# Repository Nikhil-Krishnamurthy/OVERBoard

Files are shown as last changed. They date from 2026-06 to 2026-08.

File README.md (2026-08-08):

# OVERBoard
This is my attempt at creating a custom keyboard with several unique features, this has a layer system that I have modified to work with specific tasks on my pc, I also have a 2.8 in screen to display custom text, ui, and macros. There is a full 78 led matrix, dual pi pico system, and 3 rotary encoders that interface in this system.   
# Key Features   
Full TKL Keyboard Matrix   
4 Layer Keyboard System   
3 Encoders Interfacing with the Layer System   
78 Led Matrix system   
320 x 240 2.8 inch display   
Custom UI and layer switching menus   
Computer interface and data transmission   
Custom 5A power system   

## Onshape-link:
https://cad.onshape.com/documents/a6bd6c4e9013194f1dc31777/w/de360b55982ee6c60ca7c4d4/e/a374dba059f4ceb7d8e6600d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 

# Flashing      
Flashing is done through two steps, compiling the C qmk file through QMK MSYS to compile to a uf2 file, which then can be flashed to the pi pico through holding the bootsel button and plugging it in to the usb power. Then just upload the new uf2 file to the pi pico. To flash the pi pico 2 for the display, you have to download the entire folder of the custom c++, and then through a terminal of your choice compile it. (I use vs code and i got it to work through there, idk about others). Then upload the second uf2 file to the pi pico 2 by holding the bootsel button and uploading it there.

# BOM   
78 [3 Pin Mechanical Keyboard Switches   ](https://www.amazon.com/Leezmark-Mechanical-Dustproof-Replacement-Keyboards/dp/B0GV78B48N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)   
78 [SK6812 Mini-E LEDs](https://www.amazon.com/Lizusidtsy-Similar-Individually-Addressable-500076361/dp/B0D62PYX62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)   
3 [EC11 Rotary encoders](https://www.amazon.com/CGNRONEAU-Potentiometer-Raspberry-Electronics-Projects/dp/B0G48Z8B9Q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)    
1 [Keycap Set](https://www.amazon.com/Womier-Doubleshot-Universal-Compatiability-Switches/dp/B0DD3MFZJH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)   
1 [Stabilizer Set](https://www.amazon.com/DUROCK-Stabilizers-Translucent-Keyboard-Mechanical/dp/B0B2RVN19F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)   
10 [0.1uF SMD 0805 Capacitors](https://www.digikey.com/en/products/detail/samsung-electro-mechanics/CL21B104KBCNNNC/3886661)   
2 [10uF SMD 1206 Capacitors](https://www.digikey.com/en/products/detail/taiyo-yuden/TMK316BJ106ML-T/1172143)   
83 [Through Hole Diodes](https://www.digikey.com/en/products/detail/onsemi/1N4148TR/458811)   
1 [Raspberry Pi Pico](https://www.digikey.com/en/products/detail/raspberry-pi/SC0915/13624793)   
1 [Raspberry Pi Pico 2](https://www.digikey.com/en/products/detail/raspberry-pi/SC1631/24627136)   
1 [SN74HCT245PWR](https://www.digikey.com/en/products/detail/texas-instruments/SN74HCT245PWR/376998)   
1 [Mini 560 5A 5V](https://www.amazon.com/ACEIRMC-Efficiency-Converter-Regulator-Stabilized/dp/B0C98GN9R5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)   
1 [Adafruit 5807 Power Evaluation Board](https://www.digikey.com/en/products/detail/adafruit-industries-llc/5807/21839778)   
1 [2.8 in 320 x 240 SPI Serial TFT display](https://www.amazon.com/DIANN-ILI9341-Display-320x240-Screen/dp/B0BNQBKFCT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)   
2 [PTS810_SJM_250](https://www.digikey.com/en/products/detail/c-k/PTS810SJK250SMTR-LFS/4176611)   
2 [4.7k SMD 0805 resistors](https://www.digikey.com/en/products/detail/panasonic-industry/ERA-6AEB472V/1465765)    
10 [10k SMD 0805 resistors](https://www.digikey.com/en/products/detail/stackpole-electronics-inc/RMCF0805FT10K0/1760676)   
## Extra Parts not part of BOM
9 [M3 Heat set inserts](https://www.amazon.com/HANGLIFE-Heat-Set-Threaded-Printing-Components/dp/B0CS6VZYL8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)   
9 [M3 Screws](https://www.amazon.com/Fgruh-750PCS-Assortment-Washers-Assorted/dp/B0FGV5FCBN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)   
2 [M2.5 Heat Set Inserts](https://www.amazon.com/HANGLIFE-Heat-Set-Threaded-Printing-Components/dp/B0CS6YVJYD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)   
2 [M2.5 Screws](https://www.amazon.com/Fgruh-750PCS-Assortment-Washers-Assorted/dp/B0FG2BYJSR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)   
1 [1Kg Matte Black Filament](https://www.amazon.com/ELEGOO-Filament-Dimensional-Accuracy-Carboard/dp/B0CFV3WF7P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)   
## PCB    
1 Custom Pcb    
## BOM as CSV Format    
[BOM.csv](https://github.com/Nikhil-Krishnamurthy/OVERBoard/blob/main/BOM.csv)     

# Full Render:    


# Schematic:   






# PCB:



# CAD:


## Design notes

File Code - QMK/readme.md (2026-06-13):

# overboard

overboard

*A short description of the keyboard/project*

* Keyboard Maintainer: [Nikhil-Krishnamurthy](https://github.com/Nikhil-Krishnamurthy)
* Hardware Supported: *The PCBs, controllers supported*
* Hardware Availability: *Links to where you can find this hardware*

Make example for this keyboard (after setting up your build environment):

    make overboard:default

Flashing example for this keyboard:

    make overboard:default:flash

See the [build environment setup](https://docs.qmk.fm/#/getting_started_build_tools) and the [make instructions](https://docs.qmk.fm/#/getting_started_make_guide) for more information. Brand new to QMK? Start with our [Complete Newbs Guide](https://docs.qmk.fm/#/newbs).

## Bootloader

Enter the bootloader in 3 ways:

* **Bootmagic reset**: Hold down the key at (0,0) in the matrix (usually the top left key or Escape) and plug in the keyboard
* **Physical reset button**: Briefly press the button on the back of the PCB - some may have pads you must short instead
* **Keycode in layout**: Press the key mapped to `QK_BOOT` if it is available

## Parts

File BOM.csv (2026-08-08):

Item | Quantity | Value | Link
Keyswitches | 1 | $14.99 | amazon.com/Leezmark-Mechanical-Dustproof-Replacement-Keyboards/dp/B0GV78B48N/ref=mp_s_a_1_20_sspa?crid=2GGAVKPX5GKH&dib=eyJ2IjoiMSJ9.BS9ZW8A40QZK6iI4UmdZkYcVp812RDtM8dzqQtxJq5kz5jddC0aGCLYpUDj6oWZM4geYAz7LL5dJKQJ_sMRCqYbuT9Zwzy20VnrTvVNVI-2PMGM8y_OT_gXPSKltVj0ZCmtBrzLAvtF8hVyPpS-bcG8HSGX4meJ7BWVw4GwyFBtzq-VV4k_-OB3_U29mYmabBNX5P_2u1xLUz0WsYM_SZg.sOaHXiIPD6Bd4c6RHFdcsiI9AAYZXd1oFGZit3XfvzE&dib_tag=se&keywords=mechanical+keyboard+switches&qid=1786102391&sprefix=mecha%2Caps%2C1667&sr=8-20-spons&xpid=P4xuzyhmO1Kis&sp_csd=d2lkZ2V0TmFtZT1zcF9waG9uZV9zZWFyY2hfbXRm&psc=1
SK6812 Mini-E | 1 | $10.95 | https://www.amazon.com/Lizusidtsy-Similar-Individually-Addressable-500076361/dp/B0D62PYX62?s=industrial
EC11 Rotary Encoder | 1 | $6.99 | https://www.amazon.com/CGNRONEAU-Potentiometer-Raspberry-Electronics-Projects/dp/B0G48Z8B9Q?s=industrial
Keycap Set | 1 | $13.99 | https://www.amazon.com/Womier-Doubleshot-Universal-Compatiability-Switches/dp/B0DD3MFZJH
Stabilizer Set (PCB Mount) | 1 | $18.99 | https://www.amazon.com/DUROCK-Stabilizers-Translucent-Keyboard-Mechanical/dp/B0B2RVN19F
0.1 uF 0805 Capacitor | 10 | $0.45 | https://www.digikey.com/en/products/detail/samsung-electro-mechanics/CL21B104KBCNNNC/3886661
10uF 1206 Capacitor | 2 | $0.52 | https://www.digikey.com/en/products/detail/taiyo-yuden/TMK316BJ106ML-T/1172143
1N4148TR Diode | 83 | $3.36 | https://www.digikey.com/en/products/detail/onsemi/1N4148TR/458811
Rasberry Pi Pico | 1 | $4.59 | https://www.digikey.com/en/products/detail/raspberry-pi/SC0915/13624793
Rasberry Pi Pico 2 | 1 | $6.12 | https://www.digikey.com/en/products/detail/raspberry-pi/SC1631/24627136
SN74HCT245PWR | 1 | $0.88 | https://www.digikey.com/en/products/detail/texas-instruments/SN74HCT245PWR/376998
Mini 560 5V 5A | 1 | $9.99 | https://www.amazon.com/ACEIRMC-Efficiency-Converter-Regulator-Stabilized/dp/B0C98GN9R5
Adafruit 5807 Power Delivery Board | 1 | $5.95 | https://www.digikey.com/en/products/detail/adafruit-industries-llc/5807/21839778
2.8 In SPI Display with Capacitive Touch | 1 | $11.99 | https://www.amazon.com/DIANN-ILI9341-Display-320x240-Screen/dp/B0BNQBKFCT?s=industrial
PTS810_SJM_250 | 2 | $1.16 | https://www.digikey.com/en/products/detail/c-k/PTS810SJK250SMTR-LFS/4176611
4.7k 0805 Resistor | 2 | $0.22 | https://www.digikey.com/en/products/detail/panasonic-industry/ERA-6AEB472V/1465765
10k 0805 Resistor | 10 | $0.27 | https://www.digikey.com/en/products/detail/stackpole-electronics-inc/RMCF0805FT10K0/1760676
Custom PCB | 1 | $55.60
Total |  | $167.01

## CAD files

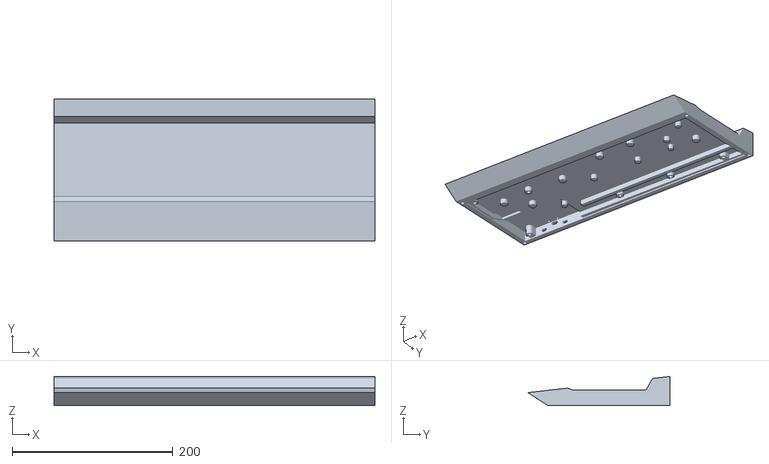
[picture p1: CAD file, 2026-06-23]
Cad-3D_Files/Keyboard_bottom.stl
398.9 x 176.7 x 36.2

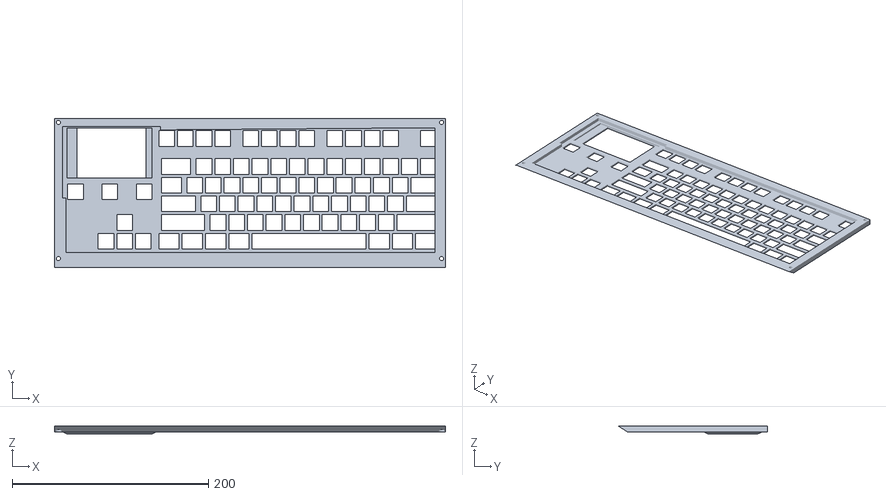
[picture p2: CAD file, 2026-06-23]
Cad-3D_Files/Keyboard_top.stl
398.9 x 151.9 x 7.80

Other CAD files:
Cad-3D_Files/Bottom_Case.step
Cad-3D_Files/Top_Case.step

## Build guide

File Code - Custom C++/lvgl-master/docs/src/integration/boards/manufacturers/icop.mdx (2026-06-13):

---
title: ICOP
description: ICOP makes industrial computer hardware and the development tools for them. ICOP offers an uncommon combination of hardware and software which distinguishes them from other board vendors.
---

ICOP makes industrial computer hardware and the development tools for them.
ICOP offers an uncommon combination of hardware and software which distinguishes
them from other board vendors.

For a start, their products are not evaluation boards. They are ready-to-use
industrial PCs. They are a complete solution electrically and mechanically.

They are programmed with the Arduino IDE. You write your embedded application
logic and UI using the Arduino framework and its library ecosystem. Arduino is a
great abstraction to solve real problems when it's available for a platform.
ICOP is one such platform. You have access to all the popular open source
Arduino libraries. There is also support for installing Windows 11 on it.

Inside most of ICOP's panel PCs is an x86 processor. They are DM&P Vortex86
series chips. They execute 32-bit i586 machine code. This has interesting
implications, especially since the programming environment is as low-level as Arduino.
It's a rare case of an x86 CPU being used in a real-time setting.

## Panel PCs

These are PCs which are designed to be mounted in a panel. They are more
powerful than typical HMIs.

### QEC-PPC-M-090T

This is an x86 panel PC which you can program using the Arduino IDE.
It has two cores. One core is dedicated to EtherCAT so the other is free
for application logic.

See the
[LVGL port repo](https://github.com/lvgl/lv_port_icop_qec_ppc_m_090t)
to get started creating a project for it with LVGL.

See the
[store page](https://www.icop.com.tw/product/QEC-PPC-M-090T)
for documentation and the ordering information.

##### Specs

CPU and Memory

- CPU: 533 MHz Vortex86EX2 32-bit x86 CPU
- RAM: 512MB/1GB DDR3
- Flash: 2GB SLC eMMC, 32MB SPI Flash

Display and Touch

- Resolution: 1024x600
- Display Size: 9"
- Interface: VGA
- Color Depth: 16-bit
- Technology: TFT
- DPI: 132 px/inch
- Touch Pad: Resistive

Connectivity

- Ethernet
- USB x3
- Headphone

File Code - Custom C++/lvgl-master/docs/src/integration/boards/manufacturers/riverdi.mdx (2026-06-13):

---
title: Riverdi
description: "Riverdi specializes in making high quality displays and the boards that carry them. They offer solutions that range from simple display panels to intelligent displays, and everything in between."
---

[Riverdi](https://riverdi.com/) specializes in making high quality
displays and the boards that carry them. They offer solutions that
range from simple display panels to intelligent displays, and
everything in between.

- STM32 Embedded Displays
- Single Board Computer Displays
- EVE Intelligent Displays
- HDMI Displays
- Evaluation Boards
- RGB, LVDS, MIPI DSI LCD Displays

## STM32 Embedded Displays

The STM32 Embedded Displays have an STM32 MCU onboard which makes
it possible to embed an entire application into the device. LVGL
is well-suited to these boards.

### lv_port_riverdi_stm32u5

[lv_port_riverdi_stm32u5](https://github.com/lvgl/lv_port_riverdi_stm32u5)
is a port repo of LVGL which supports all 5-inch Riverdi STM32
Embedded Displays.

- [RVT50HQSNWC00-B](https://riverdi.com/product/5-inch-lcd-display-capacitive-touch-panel-optical-bonding-uxtouch-stm32u5-rvt50hqsnwc00-b)
- [RVT50HQSNWC00](https://riverdi.com/product/5-inch-lcd-display-capacitive-touch-panel-air-bonding-uxtouch-stm32u5-rvt50hqsnwc00)
- [RVT50HQSFWCA0](https://riverdi.com/product/5-inch-lcd-display-capacitive-touch-panel-air-bonding-atouch-frame-stm32u5-rvt50hqsfwca0)
- [RVT50HQSNWCA0](https://riverdi.com/product/5-inch-lcd-display-capacitive-touch-panel-air-bonding-atouch-stm32u5-rvt50hqsnwca0)
- [RVT50HQSFWN00](https://riverdi.com/product/5-inch-lcd-display-stm32u5-frame-rvt50hqsfwn00)
- [RVT50HQSNWN00](https://riverdi.com/product/5-inch-lcd-display-stm32u5-rvt50hqsnwn00)

It natively supports the embedded NeoChrom GPU thanks to LVGL's support
for [NeoChrom](/integration/chip_vendors/stm32/neochrom). NemaVG --- an extension to NeoChrom's
base support --- is implemented by this MCU.

The MCU has an LCD driver peripheral which LVGL uses to update the
display. See the [LTDC](/integration/chip_vendors/stm32/ltdc) driver docs
for more info and how to customize its use.

## Single-Board Computer Displays

The Single-Board Computer Displays are ready to use with
[Toradex](/integration/boards/manufacturers/toradex) Dahlia and Mallow carrier boards. In fact,
those carrier boards are compatible with all 34-pin Riverdi
MIPI-DSI displays.

## Other Products

The **EVE Intelligent Displays** feature a Bridgetek EVE graphics
controller IC so that the display can be controlled using
high-level drawing commands over a lower-bandwidth interface than
RGB, MIPI, etc.

The **HDMI Displays** sport an HDMI interface for streamlined
integration with PCs or SBCs. These displays are still low-profile
so they can be embedded into custom fixtures with ease.

The **Evaluation Boards** are affordable carrier boards for getting
Riverdi display panels up and running before designing or buying a
carrier board for a production application.

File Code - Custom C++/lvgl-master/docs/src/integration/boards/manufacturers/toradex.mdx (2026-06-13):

---
title: Toradex
---

<br />

<hr />

## About Toradex

Toradex specializes in manufacturing high-quality embedded computing solutions
based on System on Module units (SoMs). These boards and modules are designed to
meet the needs of industrial and commercial applications, offering reliability,
longevity, and scalability. Leveraging industry-standard frameworks like Yocto
Project, Toradex enables customers to create tailored embedded systems with
ease, ensuring compatibility and flexibility.

## Products Portfolio

Toradex offers a wide range of system-on-modules (SoMs) and carrier boards
designed for various applications and industries. Here's a basic overview to
help you navigate the portfolio.

### Aquila

Aquila is a new System on Module standard expanding the Toradex portfolio to
new heights, offering unparalleled performance for computationally intensive
CPU, machine learning, and vision workloads.

To power next-gen's AI requirements in industrial and other harsh environments,
Aquila introduces a proven connector: the 400-pin board-to-board connector,
making the board extra reliable, especially in these environments.

Aquila Computer on Module:

- [Aquila iMX95](https://www.toradex.com/computer-on-modules/
      aquila-arm-family/nxp-imx95)
    - [Aquila AM69](https://www.toradex.com/computer-on-modules/
      aquila-arm-family/ti-am69)

Aquila Carrier Boards:

- [Clover](https://www.toradex.com/products/carrier-board/clover)
    - [Aquila Development Board](https://www.toradex.com/products/carrier-board/
      aquila-development-board-kit)

### Apalis

Apalis is a scalable System on Module (SoM) / Computer on Module (CoM) family
that aims to provide high performance in a compact form factor. Apalis enables
the development of advanced and robust products within a short time and with
low risks. Apalis modules scale to the highest performance in the Toradex
product range, and they provide the most interfaces of any product line on the
314-pin MXM connectors. Apalis modules are suited to a larger number of
applications in such fields as healthcare, industrial automation, robotics,
smart cities and many more. Apalis modules are supported by Toradex software
offerings and the company's rich ecosystem of other products and services.

Apalis Computer on Module:

- [Apalis iMX8](https://www.toradex.com/computer-on-modules/
      apalis-arm-family/nxp-imx-8)
    - [Apalis iMX6](https://www.toradex.com/computer-on-modules/
      apalis-arm-family/nxp-freescale-imx-6)
    - [Apalis T30](https://www.toradex.com/computer-on-modules/
      apalis-arm-family/nvidia-tegra-3)

Apalis Carrier Boards:

- [Ixora](https://www.toradex.com/products/carrier-board/
      ixora-carrier-board)
    - [Apalis Evaluation Board](https://www.toradex.com/products/carrier-board/
      ixora-carrier-board)

### Colibri

The Colibri Arm® family consists of SODIMM-sized System on Modules (SoM) /
Computer on Modules (CoM). The family offers miniaturized modules based on NXP®
i.MX 8X, i.MX 6ULL, i.MX 7, i.MX 6, Vybrid and NVIDIA® Tegra SoCs. All these
modules are pin-compatible, ensuring scalability of applications developed on
them. The Colibri family delivers cost-performance-optimized designs. An
extensive range of Colibri-compatible carrier boards and accessories, such as
cameras and displays, is also available for easy product development on the
Colibri Arm family of modules.

Colibri Computer on Module:

- [Colibri iMX8X](https://www.toradex.com/computer-on-modules/
      colibri-arm-family/nxp-imx-8x)
    - [Colibri T30](https://www.toradex.com/computer-on-modules/
      colibri-arm-family/nvidia-tegra-3)
    - [Colibri T20](https://www.toradex.com/computer-on-modules/
      colibri-arm-family/nvidia-tegra-2)
    - [Colibri iMX6](https://www.toradex.com/computer-on-modules/
      colibri-arm-family/nxp-freescale-imx6)
    - [Colibri iMX7](https://www.toradex.com/computer-on-modules/
      colibri-arm-family/nxp-freescale-imx7)
    - [Colibri iMXiMX6ULL8X](https://www.toradex.com/computer-on-modules/
      colibri-arm-family/nxp-imx6ull)
    - [Colibri VF61](https://www.toradex.com/computer-on-modules/
      colibri-arm-family/nxp-freescale-vybrid-vf6xx)
    - [Colibri VF50](https://www.toradex.com/computer-on-modules/
      colibri-arm-family/nxp-freescale-vybrid-vf5xx)

Colibri Carrier Boards:

- [Colibri Evaluation Board](https://www.toradex.com/products/carrier-board/
      colibri-evaluation-board)
    - [Iris Carrier Board](https://www.toradex.com/products/carrier-board/
      iris-carrier-board)
    - [Viola Carrier Board](https://www.toradex.com/products/carrier-board/
      viola-carrier-board)
    - [Aster Carrier Board](https://www.toradex.com/products/carrier-board/
      aster-carrier-board)

### Verdin

Verdin is a System on Module standard expanding on the successful Colibri and
Apalis form factors. It provides a revised, modern and capable interface set
and focuses on ease-of-use, robustness and being future-proof.

Verdin is similar sized to the Colibri but with a higher pin count. A DDR4
SODIMM edge connector provides a cost-effective, highly reliable, shock- and
vibration-resistant connection.

Verdin Computer on Module:

- [Verdin iMX8M Plus](https://www.toradex.com/computer-on-modules/
      verdin-arm-family/nxp-imx-8m-plus)
    - [Verdin iMX8M Mini](https://www.toradex.com/computer-on-modules/
      verdin-arm-family/nxp-imx-8m-mini-nano)
    - [Verdin AM62](https://www.toradex.com/computer-on-modules/
      verdin-arm-family/ti-am62)
    - [i.MX 95 Verdin Evaluation Kit](https://www.toradex.com/
      computer-on-modules/verdin-arm-family/nxp-imx95-evaluation-kit)
    - [Verdin iMX95](https://www.toradex.com/computer-on-modules/
      verdin-arm-family/nxp-imx95-evaluation-kit#verdin-imx95)

Verdin Carrier Boards:

- [Verdin Development Board with HDMI Adapter](https://www.toradex.com/
      products/carrier-board/verdin-development-board-kit)
    - [Dahlia Carrier Board with HDMI Adapter](https://www.toradex.com/products/
      carrier-board/dahlia-carrier-board-kit)
    - [Yavia](https://www.toradex.com/products/carrier-board/yavia)
    - [Mallow Carrier Board](https://www.toradex.com/products/carrier-board/
      mallow-carrier-board)
    - [Ivy Carrier Board](https://www.toradex.com/products/carrier-board/
      ivy-carrier-board)

## TorizonOS

TorizonOS is a Linux-based operating system developed by Toradex, tailored for
embedded systems. It is designed to simplify the development, deployment, and
maintenance of applications, especially in industrial and IoT settings.
Combining ease of use with powerful features like containerization and
over-the-air (OTA) updates, TorizonOS helps developers accelerate
time-to-market while ensuring robust performance and security for embedded
applications.

A TorizonOS guide to develop an application using LVGL can be found in the
[Torizon OS](/integration/embedded_linux/distros/torizon) section.

More information is provided in the [Torizon documentation](https://www.torizon.
io/torizon-os).

## Toradex Examples

There are existing ready to use repositories available. Click [here](https://
github.com/lvgl?q=lv_port_toradex&type=all&language=&sort=) to check them out.

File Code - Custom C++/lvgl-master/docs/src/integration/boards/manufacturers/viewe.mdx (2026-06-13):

---
title: Viewe
description: "Viewe specializes in comprehensive display solutions for more than 10 Years with remarkable capability of software and hardware R&D, factory manufacturing and sales service. Viewe not only offers o..."
---

[Viewe](https://viewedisplay.com/) specializes in comprehensive display solutions
for more than 10 Years with remarkable capability of software and hardware R&D,
factory manufacturing and sales service. Viewe not only offers one-stop
[bare display and touch solutions](https://viewedisplay.com/display-solutions/)
but also [embedded smart displays](https://viewedisplay.com/smart-solutions/)
with standard productions and tailored customization to develop your concepts
to reality.

## Products Portfolio:

- Embedded Smart Displays
  
    - [IOT_AIOT Smart Display](https://viewedisplay.com/iot_aiot-smart-display/)
    - [Uart Smart Display](https://viewedisplay.com/uart-smart-display/)
    - [HDMI Display_Raspberry Pi Display](https://viewedisplay.com/hdmi-display-raspberry-pi-display/)
    - Arduino Display

TFT | OLED Display

- [Sunlight Readable Display](https://viewedisplay.com/sunlight-readable-display/)
    - [AMOLED Displays](https://viewedisplay.com/amoled-display-list/)
    - [Transflective TFT Displays](https://viewedisplay.com/transflective-tft-display/)
    - [Standard TFT Displays](https://viewedisplay.com/standard-display/)
    - [Bar Display/Stretched TFT Display](https://viewedisplay.com/bar-display-stretched-display/)
    - [Square TFT Display](https://viewedisplay.com/square-display/)
    - [Round TFT Display](https://viewedisplay.com/round-display/)

## IOT AIOT Smart Displays

The Viewe IOT AIOT Smart Displays are a series of displays that use ESP32
microcontrollers with integrated multi-modal interactions of GUI/voice/camera, ML/AI
edge computing, and seamless connectivity. UART/RS232/RS485/CAN Interfaces and
redundant IO interfaces are included to facilitate extended usage. LVGL/Arduino/ESP-IDF
is well-suited to these boards.

### lv_port_viewe_7_espidf

[lv_port_viewe_7_espidf](https://github.com/lvgl/lv_port_viewe_7_espidf)
is a port repository of LVGL which supports Viewe ESP32 S3 Smart Display 7.0 inch.
It is based on ESP-IDF and uses the ESP32-S3 microcontroller.

- [Viewe ESP32 S3 Smart Display](https://viewedisplay.com/product/esp32-7-inch-800x480-rgb-ips-tft-display-touch-screen-arduino-lvgl-uart/)

### lv_port_viewe_knob_15_espidf

[lv_port_viewe_knob_15_espidf](https://github.com/lvgl/lv_port_viewe_knob_15_espidf)
is a port repository of LVGL which supports Viewe AMOLED Touch Knob Display.
It is based on ESP-IDF and uses the ESP32-S3 microcontroller.

- [Viewe AMOLED Touch Knob Display](https://viewedisplay.com/product/esp32-1-5-inch-466x466-round-amoled-knob-display-touch-screen-arduino-lvgl/)

## UART Smart Displays

The Viewe UART Smart Displays are a series of displays that use ESP32 and STM32
microcontrollers with UART/RS232/RS485/CAN Interface and have IO interface for
connecting to peripherals. LVGL is well-suited to these boards.

### lv_port_viewe_7_espidf

[lv_port_viewe_7_espidf](https://github.com/lvgl/lv_port_viewe_7_espidf)
is a port repository of LVGL which supports Viewe ESP32 S3 Smart Display 7.0 inch.
It is based on ESP-IDF and uses the ESP32-S3 microcontroller.

- [Viewe ESP32 S3 Smart Display](https://viewedisplay.com/product/esp32-7-inch-800x480-rgb-ips-tft-display-touch-screen-arduino-lvgl-uart/)

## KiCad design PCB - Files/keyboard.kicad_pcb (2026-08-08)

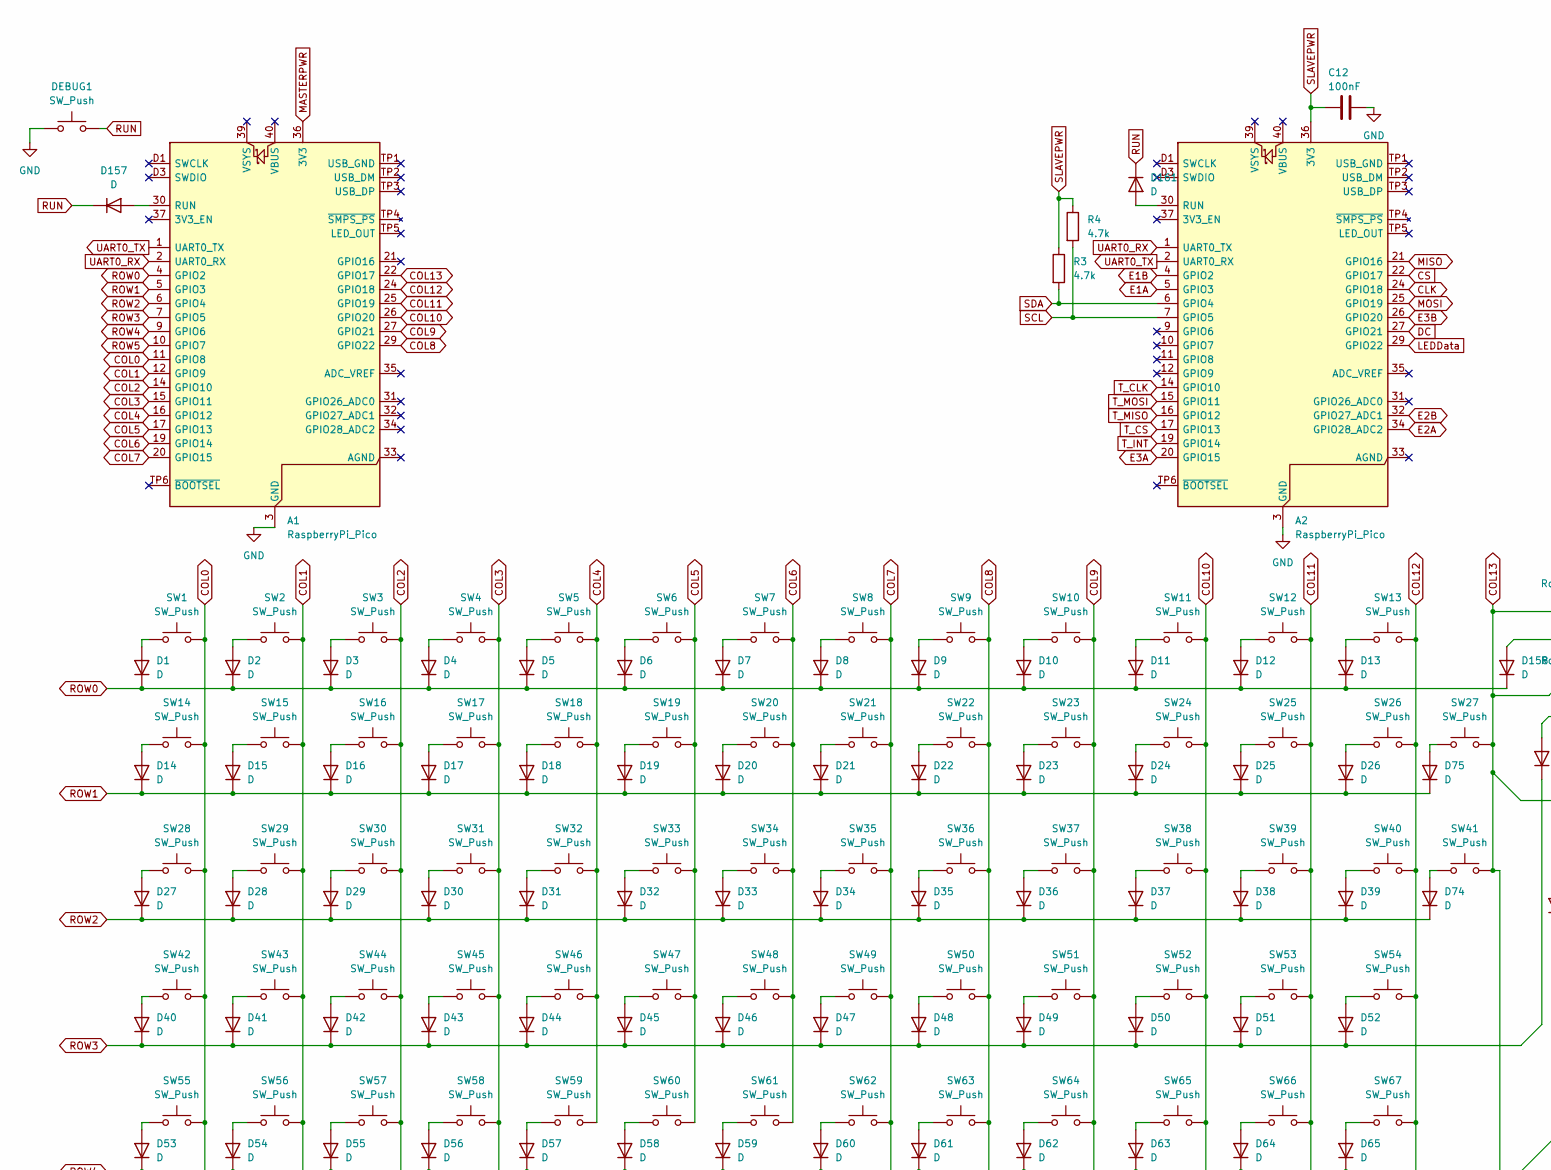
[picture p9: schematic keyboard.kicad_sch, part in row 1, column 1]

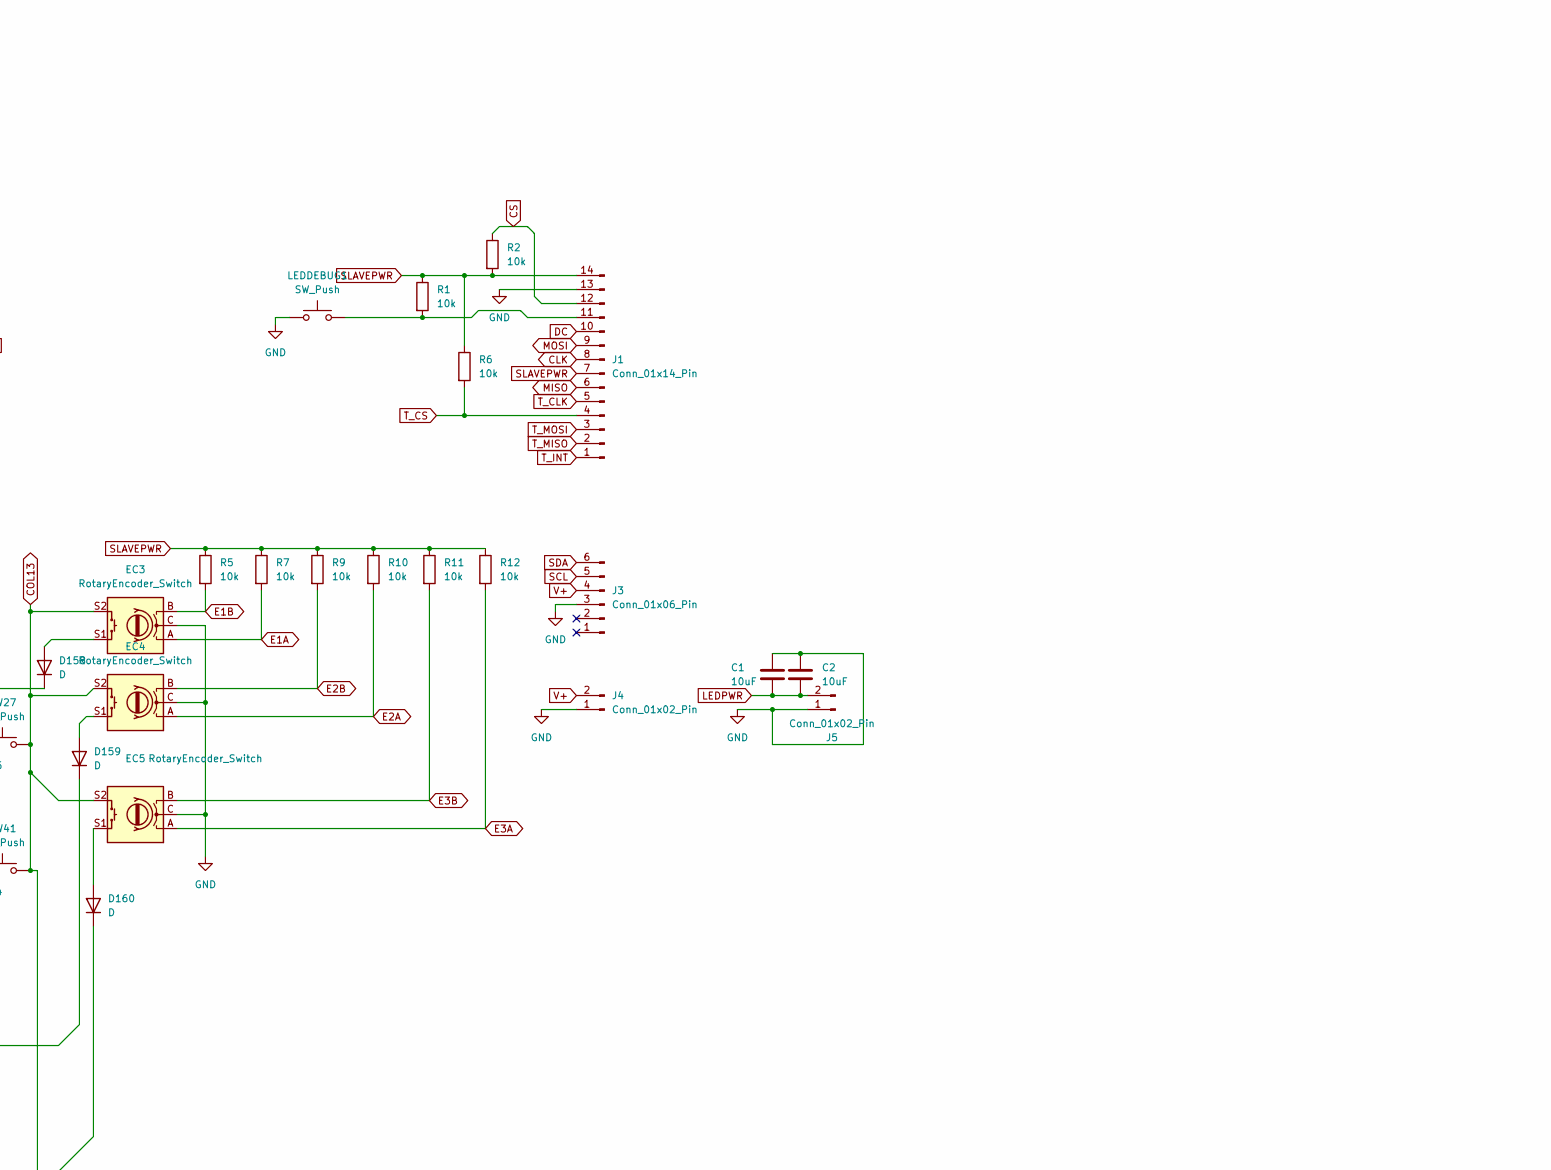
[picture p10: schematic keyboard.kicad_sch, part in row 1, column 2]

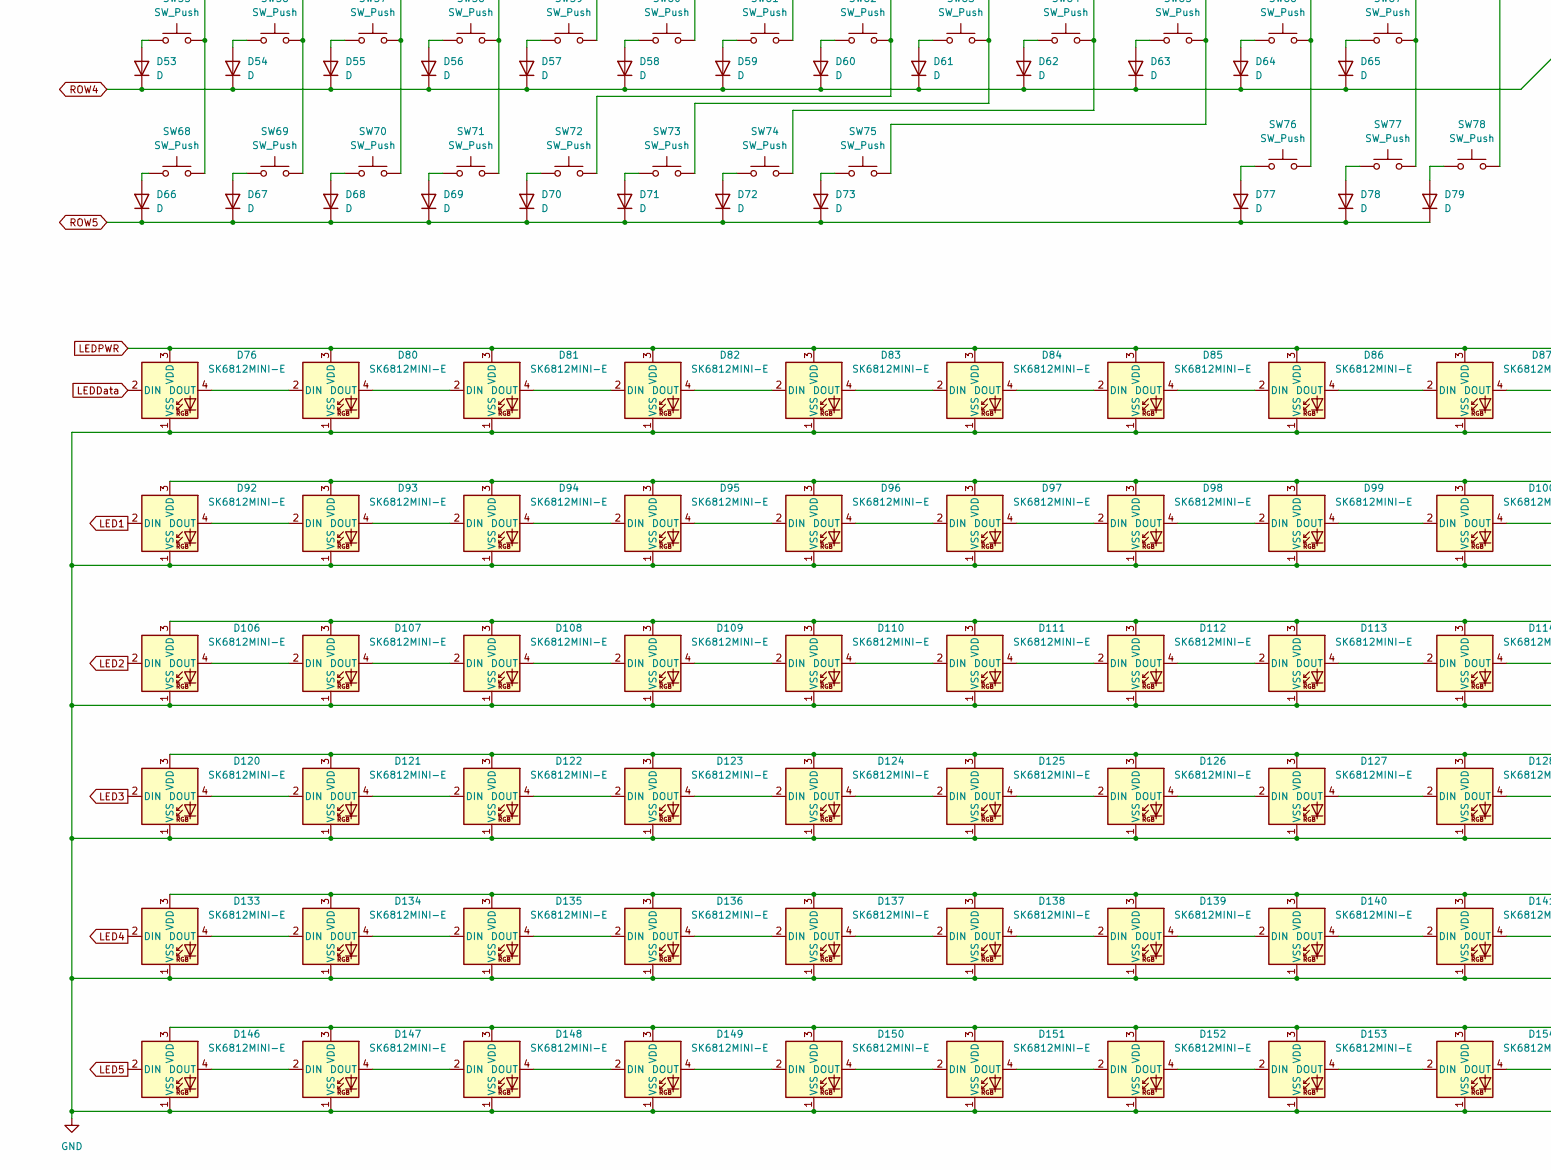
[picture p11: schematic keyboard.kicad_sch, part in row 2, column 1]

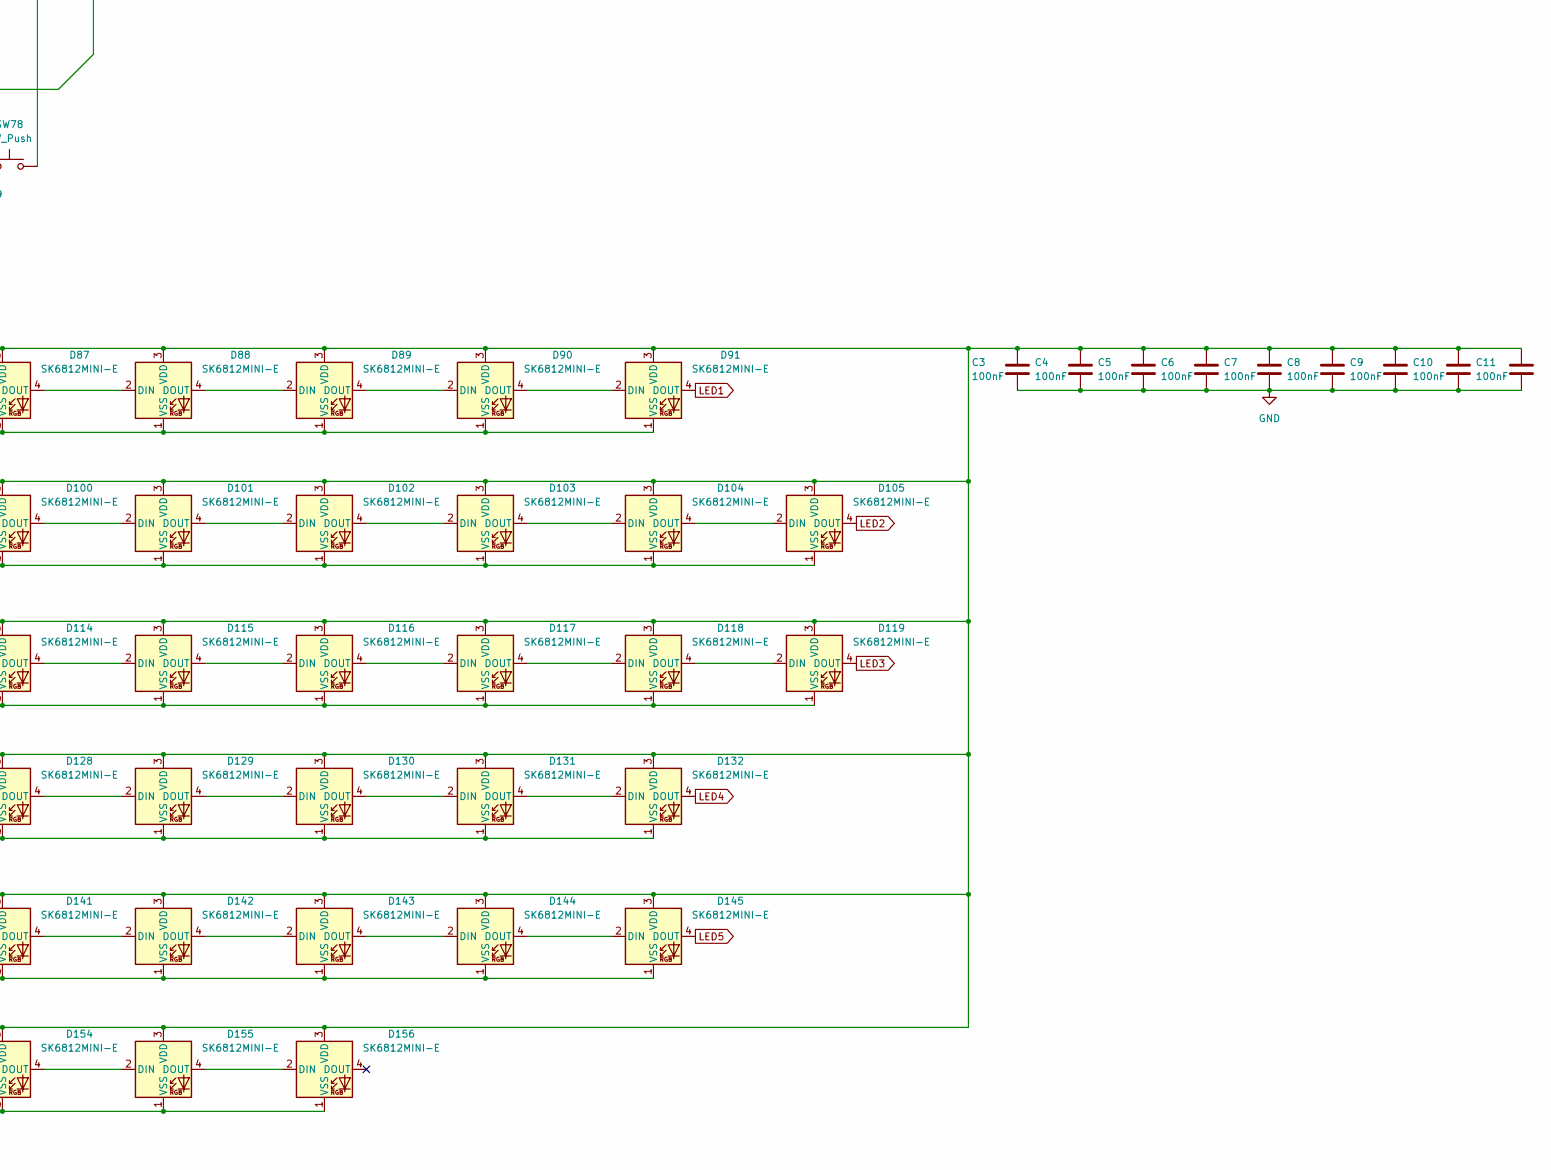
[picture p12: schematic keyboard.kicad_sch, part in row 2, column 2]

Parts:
A1, A2: RaspberryPi_Pico; RaspberryPi_Pico_Common_THT
C1, C2: 10uF; C_1206_3216Metric_Pad1.33x1.80mm_HandSolder
C3, C4, C5, C6, C7, C8, C9, C10, C11, C12: 100nF; C_0805_2012Metric_Pad1.18x1.45mm_HandSolder
D1, D2, D3, D4, D5, D6, D7, D8, D9, D10, D11, D12, D13, D14, D15, D16, D17, D18, D19, D20, D21, D22, D23, D24, D25, D26, D27, D28, D29, D30, D31, D32, D33, D34, D35, D36, D37, D38, D39, D40, D41, D42, D43, D44, D45, D46, D47, D48, D49, D50, D51, D52, D53, D54, D55, D56, D57, D58, D59, D60, D61, D62, D63, D64, D65, D66, D67, D68, D69, D70, D71, D72, D73, D74, D75, D77, D78, D79, D157, D158, D159, D160, D161: D; D_DO-35_SOD27_P7.62mm_Horizontal
D76, D80, D81, D82, D83, D84, D85, D86, D87, D88, D89, D90, D91, D92, D93, D94, D95, D96, D97, D98, D99, D100, D101, D102, D103, D104, D105, D106, D107, D108, D109, D110, D111, D112, D113, D114, D115, D116, D117, D118, D119, D120, D121, D122, D123, D124, D125, D126, D127, D128, D129, D130, D131, D132, D133, D134, D135, D136, D137, D138, D139, D140, D141, D142, D143, D144, D145, D146, D147, D148, D149, D150, D151, D152, D153, D154, D155, D156: SK6812MINI-E; LED_SK6812MINI-E_3.2x2.8mm_P1.5mm_ReverseMount
DEBUG1: SW_Push; SW_PTS810_SJM_250_SMTR_LFS
EC3, EC4, EC5: RotaryEncoder_Switch; RotaryEncoder_Alps_EC11E-Switch_Vertical_H20mm
J1: Conn_01x14_Pin; PinHeader_1x14_P2.54mm_Vertical
J3: Conn_01x06_Pin; PinHeader_1x06_P2.54mm_Vertical
J4, J5: Conn_01x02_Pin; PinHeader_1x02_P2.54mm_Vertical
LEDDEBUG1: SW_Push; SW_PTS810_SJM_250_SMTR_LFS
R1, R2, R5, R6, R7, R9, R10, R11, R12: 10k; R_0805_2012Metric_Pad1.20x1.40mm_HandSolder
R3, R4: 4.7k; R_0805_2012Metric_Pad1.20x1.40mm_HandSolder
SW1, SW2, SW3, SW4, SW5, SW6, SW7, SW8, SW9, SW10, SW11, SW12, SW13, SW14, SW15, SW16, SW17, SW18, SW19, SW20, SW21, SW22, SW23, SW24, SW25, SW26, SW29, SW30, SW31, SW32, SW33, SW34, SW35, SW36, SW37, SW38, SW39, SW40, SW43, SW44, SW45, SW46, SW47, SW48, SW49, SW50, SW51, SW52, SW53, SW56, SW57, SW58, SW59, SW60, SW61, SW62, SW63, SW64, SW65, SW67, SW76, SW77, SW78: SW_Push; SW_Cherry_MX_1.00u_PCB
SW27: SW_Push; SW_Cherry_MX_2.00u_PCB
SW28, SW41, SW42: SW_Push; SW_Cherry_MX_1.50u_PCB
SW54, SW55: SW_Push; SW_Cherry_MX_2.25u_PCB
SW66: SW_Push; SW_Cherry_MX_2.75u_PCB
SW68, SW69, SW70, SW72, SW73, SW74, SW75: SW_Push; SW_Cherry_MX_1.25u_PCB
SW71: SW_Push; SW_Cherry_MX_6.25u_PCB

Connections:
CLK: A2.24 (GPIO18), J1.8
COL0: A1.11 (GPIO8), SW1.2, SW14.2, SW28.2, SW42.2, SW55.2, SW68.2
COL1: A1.12 (GPIO9), SW2.2, SW15.2, SW29.2, SW43.2, SW56.2, SW69.2
COL2: A1.14 (GPIO10), SW3.2, SW16.2, SW30.2, SW44.2, SW57.2, SW70.2
COL3: A1.15 (GPIO11), SW4.2, SW17.2, SW31.2, SW45.2, SW58.2, SW71.2
COL4: A1.16 (GPIO12), SW5.2, SW18.2, SW32.2, SW46.2, SW59.2
COL5: A1.17 (GPIO13), SW6.2, SW19.2, SW33.2, SW47.2, SW60.2
COL6: A1.19 (GPIO14), SW7.2, SW20.2, SW34.2, SW48.2, SW61.2
COL7: A1.20 (GPIO15), SW8.2, SW21.2, SW35.2, SW49.2, SW62.2, SW72.2
COL8: A1.29 (GPIO22), SW9.2, SW22.2, SW36.2, SW50.2, SW63.2, SW73.2
COL9: A1.27 (GPIO21), SW10.2, SW23.2, SW37.2, SW51.2, SW64.2, SW74.2
COL10: A1.26 (GPIO20), SW11.2, SW24.2, SW38.2, SW52.2, SW65.2, SW75.2
COL11: A1.25 (GPIO19), SW12.2, SW25.2, SW39.2, SW53.2, SW66.2, SW76.2
COL12: A1.24 (GPIO18), SW13.2, SW26.2, SW40.2, SW54.2, SW67.2, SW77.2
COL13: A1.22 (GPIO17), EC3.S2, EC4.S2, EC5.S2, SW27.2, SW41.2, SW78.2
CS: A2.22 (GPIO17), J1.12, R2.1
DC: A2.27 (GPIO21), J1.10
E1A: A2.5 (GPIO3), EC3.A, R7.2
E1B: A2.4 (GPIO2), EC3.B, R5.2
E2A: A2.34 (GPIO28_ADC2), EC4.A, R10.2
E2B: A2.32 (GPIO27_ADC1), EC4.B, R9.2
E3A: A2.20 (GPIO15), EC5.A, R12.2
E3B: A2.26 (GPIO20), EC5.B, R11.2
GND: A1.3 (GND), A1.8 (GND), A1.13 (GND), A1.18 (GND), A1.23 (GND), A1.28 (GND), A1.38 (GND), A1.D2 (GND), A2.3 (GND), A2.8 (GND), A2.13 (GND), A2.18 (GND), A2.23 (GND), A2.28 (GND), A2.38 (GND), A2.D2 (GND), C1.1, C2.2, C3.2, C4.2, C5.2, C6.2, C7.2, C8.2, C9.2, C10.2, C11.2, C12.1, D76.1 (VSS), D80.1 (VSS), D81.1 (VSS), D82.1 (VSS), D83.1 (VSS), D84.1 (VSS), D85.1 (VSS), D86.1 (VSS), D87.1 (VSS), D88.1 (VSS), D89.1 (VSS), D90.1 (VSS), D91.1 (VSS), D92.1 (VSS), D93.1 (VSS), D94.1 (VSS), D95.1 (VSS), D96.1 (VSS), D97.1 (VSS), D98.1 (VSS), D99.1 (VSS), D100.1 (VSS), D101.1 (VSS), D102.1 (VSS), D103.1 (VSS), D104.1 (VSS), D105.1 (VSS), D106.1 (VSS), D107.1 (VSS), D108.1 (VSS), D109.1 (VSS), D110.1 (VSS), D111.1 (VSS), D112.1 (VSS), D113.1 (VSS), D114.1 (VSS), D115.1 (VSS), D116.1 (VSS), D117.1 (VSS), D118.1 (VSS), D119.1 (VSS), D120.1 (VSS), D121.1 (VSS), D122.1 (VSS), D123.1 (VSS), D124.1 (VSS), D125.1 (VSS), D126.1 (VSS), D127.1 (VSS), D128.1 (VSS), D129.1 (VSS), D130.1 (VSS), D131.1 (VSS), D132.1 (VSS), D133.1 (VSS), D134.1 (VSS), D135.1 (VSS), D136.1 (VSS), D137.1 (VSS), D138.1 (VSS), D139.1 (VSS), D140.1 (VSS), D141.1 (VSS), D142.1 (VSS), D143.1 (VSS), D144.1 (VSS), D145.1 (VSS), D146.1 (VSS), D147.1 (VSS), D148.1 (VSS), D149.1 (VSS), D150.1 (VSS), D151.1 (VSS), D152.1 (VSS), D153.1 (VSS), D154.1 (VSS), D155.1 (VSS), D156.1 (VSS), DEBUG1.1, EC3.C, EC4.C, EC5.C, J1.13, J3.3, J4.1, J5.1, LEDDEBUG1.1
LED1: D91.4 (DOUT), D92.2 (DIN)
LED2: D105.4 (DOUT), D106.2 (DIN)
LED3: D119.4 (DOUT), D120.2 (DIN)
LED4: D132.4 (DOUT), D133.2 (DIN)
LED5: D145.4 (DOUT), D146.2 (DIN)
LEDData: A2.29 (GPIO22), D76.2 (DIN)
LEDPWR: C1.2, C2.1, C3.1, C4.1, C5.1, C6.1, C7.1, C8.1, C9.1, C10.1, C11.1, D76.3 (VDD), D80.3 (VDD), D81.3 (VDD), D82.3 (VDD), D83.3 (VDD), D84.3 (VDD), D85.3 (VDD), D86.3 (VDD), D87.3 (VDD), D88.3 (VDD), D89.3 (VDD), D90.3 (VDD), D91.3 (VDD), D92.3 (VDD), D93.3 (VDD), D94.3 (VDD), D95.3 (VDD), D96.3 (VDD), D97.3 (VDD), D98.3 (VDD), D99.3 (VDD), D100.3 (VDD), D101.3 (VDD), D102.3 (VDD), D103.3 (VDD), D104.3 (VDD), D105.3 (VDD), D106.3 (VDD), D107.3 (VDD), D108.3 (VDD), D109.3 (VDD), D110.3 (VDD), D111.3 (VDD), D112.3 (VDD), D113.3 (VDD), D114.3 (VDD), D115.3 (VDD), D116.3 (VDD), D117.3 (VDD), D118.3 (VDD), D119.3 (VDD), D120.3 (VDD), D121.3 (VDD), D122.3 (VDD), D123.3 (VDD), D124.3 (VDD), D125.3 (VDD), D126.3 (VDD), D127.3 (VDD), D128.3 (VDD), D129.3 (VDD), D130.3 (VDD), D131.3 (VDD), D132.3 (VDD), D133.3 (VDD), D134.3 (VDD), D135.3 (VDD), D136.3 (VDD), D137.3 (VDD), D138.3 (VDD), D139.3 (VDD), D140.3 (VDD), D141.3 (VDD), D142.3 (VDD), D143.3 (VDD), D144.3 (VDD), D145.3 (VDD), D146.3 (VDD), D147.3 (VDD), D148.3 (VDD), D149.3 (VDD), D150.3 (VDD), D151.3 (VDD), D152.3 (VDD), D153.3 (VDD), D154.3 (VDD), D155.3 (VDD), D156.3 (VDD), J5.2
MASTERPWR: A1.36 (3V3)
MISO: A2.21 (GPIO16), J1.6
MOSI: A2.25 (GPIO19), J1.9
unnamed: A1.30 (RUN), D157.2 (A)
unnamed: A2.30 (RUN), D161.2 (A)
unnamed: D1.2 (A), SW1.1
unnamed: D2.2 (A), SW2.1
unnamed: D3.2 (A), SW3.1
unnamed: D4.2 (A), SW4.1
unnamed: D5.2 (A), SW5.1
unnamed: D6.2 (A), SW6.1
unnamed: D7.2 (A), SW7.1
unnamed: D8.2 (A), SW8.1
unnamed: D9.2 (A), SW9.1
unnamed: D10.2 (A), SW10.1
unnamed: D11.2 (A), SW11.1
unnamed: D12.2 (A), SW12.1
unnamed: D13.2 (A), SW13.1
unnamed: D14.2 (A), SW14.1
unnamed: D15.2 (A), SW15.1
unnamed: D16.2 (A), SW16.1
unnamed: D17.2 (A), SW17.1
unnamed: D18.2 (A), SW18.1
unnamed: D19.2 (A), SW19.1
unnamed: D20.2 (A), SW20.1
unnamed: D21.2 (A), SW21.1
unnamed: D22.2 (A), SW22.1
unnamed: D23.2 (A), SW23.1
unnamed: D24.2 (A), SW24.1
unnamed: D25.2 (A), SW25.1
unnamed: D26.2 (A), SW26.1
unnamed: D27.2 (A), SW28.1
unnamed: D28.2 (A), SW29.1
unnamed: D29.2 (A), SW30.1
unnamed: D30.2 (A), SW31.1
unnamed: D31.2 (A), SW32.1
unnamed: D32.2 (A), SW33.1
unnamed: D33.2 (A), SW34.1
unnamed: D34.2 (A), SW35.1
unnamed: D35.2 (A), SW36.1
unnamed: D36.2 (A), SW37.1
unnamed: D37.2 (A), SW38.1
unnamed: D38.2 (A), SW39.1
unnamed: D39.2 (A), SW40.1
unnamed: D40.2 (A), SW42.1
unnamed: D41.2 (A), SW43.1
unnamed: D42.2 (A), SW44.1
unnamed: D43.2 (A), SW45.1
unnamed: D44.2 (A), SW46.1
unnamed: D45.2 (A), SW47.1
unnamed: D46.2 (A), SW48.1
unnamed: D47.2 (A), SW49.1
unnamed: D48.2 (A), SW50.1
unnamed: D49.2 (A), SW51.1
unnamed: D50.2 (A), SW52.1
unnamed: D51.2 (A), SW53.1
unnamed: D52.2 (A), SW54.1
unnamed: D53.2 (A), SW55.1
unnamed: D54.2 (A), SW56.1
unnamed: D55.2 (A), SW57.1
unnamed: D56.2 (A), SW58.1
unnamed: D57.2 (A), SW59.1
unnamed: D58.2 (A), SW60.1
unnamed: D59.2 (A), SW61.1
unnamed: D60.2 (A), SW62.1
unnamed: D61.2 (A), SW63.1
unnamed: D62.2 (A), SW64.1
unnamed: D63.2 (A), SW65.1
unnamed: D64.2 (A), SW66.1
unnamed: D65.2 (A), SW67.1
unnamed: D66.2 (A), SW68.1
unnamed: D67.2 (A), SW69.1
unnamed: D68.2 (A), SW70.1
unnamed: D69.2 (A), SW71.1
unnamed: D70.2 (A), SW72.1
unnamed: D71.2 (A), SW73.1
unnamed: D72.2 (A), SW74.1
unnamed: D73.2 (A), SW75.1
unnamed: D74.2 (A), SW41.1
unnamed: D75.2 (A), SW27.1
unnamed: D76.4 (DOUT), D80.2 (DIN)
unnamed: D77.2 (A), SW76.1
unnamed: D78.2 (A), SW77.1
unnamed: D79.2 (A), SW78.1
unnamed: D80.4 (DOUT), D81.2 (DIN)
unnamed: D81.4 (DOUT), D82.2 (DIN)
unnamed: D82.4 (DOUT), D83.2 (DIN)
unnamed: D83.4 (DOUT), D84.2 (DIN)
unnamed: D84.4 (DOUT), D85.2 (DIN)
unnamed: D85.4 (DOUT), D86.2 (DIN)
unnamed: D86.4 (DOUT), D87.2 (DIN)
unnamed: D87.4 (DOUT), D88.2 (DIN)
unnamed: D88.4 (DOUT), D89.2 (DIN)
unnamed: D89.4 (DOUT), D90.2 (DIN)
unnamed: D90.4 (DOUT), D91.2 (DIN)
unnamed: D92.4 (DOUT), D93.2 (DIN)
unnamed: D93.4 (DOUT), D94.2 (DIN)
unnamed: D94.4 (DOUT), D95.2 (DIN)
unnamed: D95.4 (DOUT), D96.2 (DIN)
unnamed: D96.4 (DOUT), D97.2 (DIN)
unnamed: D97.4 (DOUT), D98.2 (DIN)
unnamed: D98.4 (DOUT), D99.2 (DIN)
unnamed: D99.4 (DOUT), D100.2 (DIN)
unnamed: D100.4 (DOUT), D101.2 (DIN)
unnamed: D101.4 (DOUT), D102.2 (DIN)
unnamed: D102.4 (DOUT), D103.2 (DIN)
unnamed: D103.4 (DOUT), D104.2 (DIN)
unnamed: D104.4 (DOUT), D105.2 (DIN)
unnamed: D106.4 (DOUT), D107.2 (DIN)
unnamed: D107.4 (DOUT), D108.2 (DIN)
unnamed: D108.4 (DOUT), D109.2 (DIN)
unnamed: D109.4 (DOUT), D110.2 (DIN)
unnamed: D110.4 (DOUT), D111.2 (DIN)
unnamed: D111.4 (DOUT), D112.2 (DIN)
unnamed: D112.4 (DOUT), D113.2 (DIN)
unnamed: D113.4 (DOUT), D114.2 (DIN)
unnamed: D114.4 (DOUT), D115.2 (DIN)
unnamed: D115.4 (DOUT), D116.2 (DIN)
unnamed: D116.4 (DOUT), D117.2 (DIN)
unnamed: D117.4 (DOUT), D118.2 (DIN)
unnamed: D118.4 (DOUT), D119.2 (DIN)
unnamed: D120.4 (DOUT), D121.2 (DIN)
unnamed: D121.4 (DOUT), D122.2 (DIN)
unnamed: D122.4 (DOUT), D123.2 (DIN)
unnamed: D123.4 (DOUT), D124.2 (DIN)
unnamed: D124.4 (DOUT), D125.2 (DIN)
unnamed: D125.4 (DOUT), D126.2 (DIN)
unnamed: D126.4 (DOUT), D127.2 (DIN)
unnamed: D127.4 (DOUT), D128.2 (DIN)
unnamed: D128.4 (DOUT), D129.2 (DIN)
unnamed: D129.4 (DOUT), D130.2 (DIN)
unnamed: D130.4 (DOUT), D131.2 (DIN)
unnamed: D131.4 (DOUT), D132.2 (DIN)
unnamed: D133.4 (DOUT), D134.2 (DIN)
unnamed: D134.4 (DOUT), D135.2 (DIN)
unnamed: D135.4 (DOUT), D136.2 (DIN)
unnamed: D136.4 (DOUT), D137.2 (DIN)
unnamed: D137.4 (DOUT), D138.2 (DIN)
unnamed: D138.4 (DOUT), D139.2 (DIN)
unnamed: D139.4 (DOUT), D140.2 (DIN)
unnamed: D140.4 (DOUT), D141.2 (DIN)
unnamed: D141.4 (DOUT), D142.2 (DIN)
unnamed: D142.4 (DOUT), D143.2 (DIN)
unnamed: D143.4 (DOUT), D144.2 (DIN)
unnamed: D144.4 (DOUT), D145.2 (DIN)
unnamed: D146.4 (DOUT), D147.2 (DIN)
unnamed: D147.4 (DOUT), D148.2 (DIN)
unnamed: D148.4 (DOUT), D149.2 (DIN)
unnamed: D149.4 (DOUT), D150.2 (DIN)
unnamed: D150.4 (DOUT), D151.2 (DIN)
unnamed: D151.4 (DOUT), D152.2 (DIN)
unnamed: D152.4 (DOUT), D153.2 (DIN)
unnamed: D153.4 (DOUT), D154.2 (DIN)
unnamed: D154.4 (DOUT), D155.2 (DIN)
unnamed: D155.4 (DOUT), D156.2 (DIN)
unnamed: D158.2 (A), EC3.S1
unnamed: D159.2 (A), EC4.S1
unnamed: D160.2 (A), EC5.S1
unnamed: J1.11, LEDDEBUG1.2, R1.2
ROW0: A1.4 (GPIO2), D1.1 (K), D2.1 (K), D3.1 (K), D4.1 (K), D5.1 (K), D6.1 (K), D7.1 (K), D8.1 (K), D9.1 (K), D10.1 (K), D11.1 (K), D12.1 (K), D13.1 (K), D158.1 (K)
ROW1: A1.5 (GPIO3), D14.1 (K), D15.1 (K), D16.1 (K), D17.1 (K), D18.1 (K), D19.1 (K), D20.1 (K), D21.1 (K), D22.1 (K), D23.1 (K), D24.1 (K), D25.1 (K), D26.1 (K), D75.1 (K)
ROW2: A1.6 (GPIO4), D27.1 (K), D28.1 (K), D29.1 (K), D30.1 (K), D31.1 (K), D32.1 (K), D33.1 (K), D34.1 (K), D35.1 (K), D36.1 (K), D37.1 (K), D38.1 (K), D39.1 (K), D74.1 (K)
ROW3: A1.7 (GPIO5), D40.1 (K), D41.1 (K), D42.1 (K), D43.1 (K), D44.1 (K), D45.1 (K), D46.1 (K), D47.1 (K), D48.1 (K), D49.1 (K), D50.1 (K), D51.1 (K), D52.1 (K), D159.1 (K)
ROW4: A1.9 (GPIO6), D53.1 (K), D54.1 (K), D55.1 (K), D56.1 (K), D57.1 (K), D58.1 (K), D59.1 (K), D60.1 (K), D61.1 (K), D62.1 (K), D63.1 (K), D64.1 (K), D65.1 (K), D160.1 (K)
ROW5: A1.10 (GPIO7), D66.1 (K), D67.1 (K), D68.1 (K), D69.1 (K), D70.1 (K), D71.1 (K), D72.1 (K), D73.1 (K), D77.1 (K), D78.1 (K), D79.1 (K)
RUN: D157.1 (K), D161.1 (K), DEBUG1.2
SCL: A2.7 (GPIO5), J3.5 (SCL), R4.2
SDA: A2.6 (GPIO4), J3.6, R3.2
SLAVEPWR: A2.36 (3V3), C12.2, J1.7, J1.14, R1.1, R2.2, R3.1, R4.1, R5.1, R6.1, R7.1, R9.1, R10.1, R11.1, R12.1
T_CLK: A2.14 (GPIO10), J1.5
T_CS: A2.17 (GPIO13), J1.4, R6.2
T_INT: A2.19 (GPIO14), J1.1
T_MISO: A2.16 (GPIO12), J1.2
T_MOSI: A2.15 (GPIO11), J1.3
UART0_RX: A1.2 (UART0_RX), A2.1 (UART0_TX)
UART0_TX: A1.1 (UART0_TX), A2.2 (UART0_RX)
V+: J3.4, J4.2

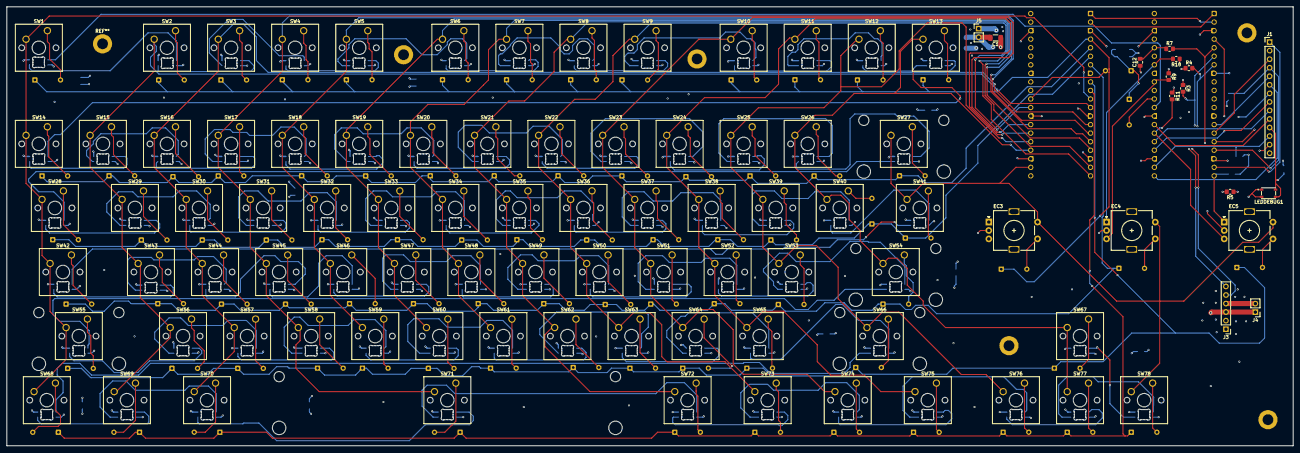
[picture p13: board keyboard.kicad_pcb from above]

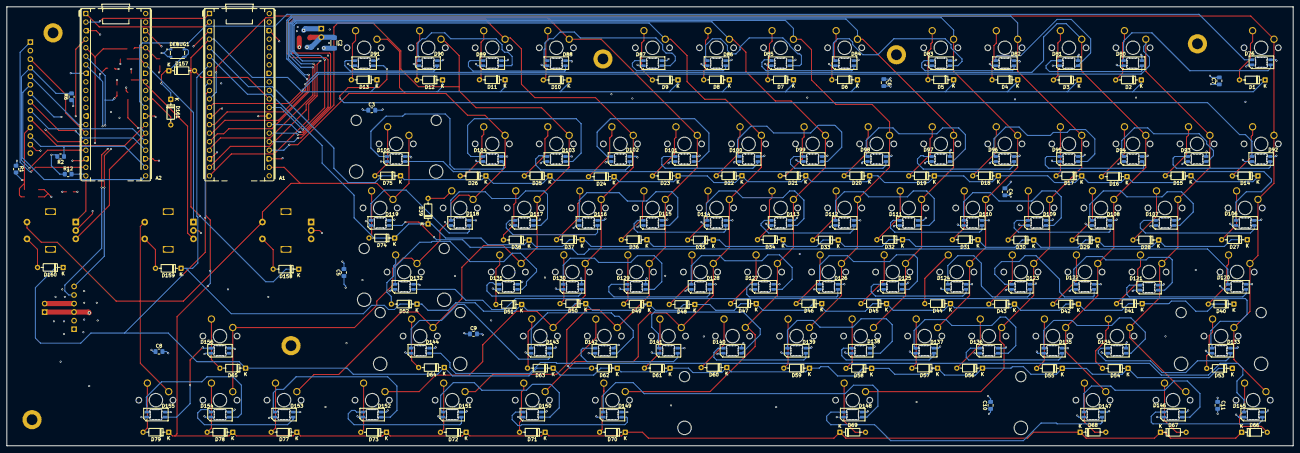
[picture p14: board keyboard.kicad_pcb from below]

Board: 4 copper layers, 382.5 x 130.5 mm, 273 parts (178 on the bottom side), 207 nets.

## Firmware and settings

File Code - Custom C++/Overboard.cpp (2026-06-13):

#include <stdio.h>
#include "pico/stdlib.h"
#include "hardware/spi.h"
#include "hardware/i2c.h"
#include "hardware/pio.h"
#include "hardware/uart.h"
#include "pico/multicore.h"
#include "lvgl_helper.h"

#include "lvgl-master/lvgl.h"
#include "ili9341.h"

#include "total_init.h"
#include "uart_control.h"
#include "spi_control.h"
#include "i2c_control.h"
#include "encoder_manager.h"
#include "song_info.h"

#define TFT_HOR_RES 320
#define TFT_VER_RES 240

uint32_t current_time = 0;
uint32_t ellapsed_time = 0;


static uint32_t my_tick_cb(void)
{
    return to_ms_since_boot(get_absolute_time());
}

static void my_flush_cb(lv_display_t * disp, const lv_area_t * area, uint8_t * px_map)
{
    /*Write px_map to the area->x1, area->x2, area->y1, area->y2 area of the
     *frame buffer or external display controller. */
    uint16_t w = (area->x2 - area->x1) + 1;
    uint16_t h = (area->y2 - area->y1) + 1;

    // 2. Cast the raw uint8_t byte pointer to a 16-bit pointer (RGB565) 
    // because your driver handles 16-bit pixel data blocks
    uint16_t * bitmap = (uint16_t *)px_map;

    // 3. Pass everything directly into your hardware driver function
    LCD_WriteBitmap(area->x1, area->y1, w, h, bitmap);
    /* signal LVGL that we're done */
    lv_display_flush_ready(disp);
}

/*static void my_touch_read_cb(lv_indev_t * indev, lv_indev_data_t * data)
{
   if(my_touch_is_pressed()) {
       data->point.x = touchpad_x;
       data->point.y = touchpad_y;
       data->state = LV_INDEV_STATE_PRESSED;
   } else {
       data->state = LV_INDEV_STATE_RELEASED;
   }
}*/

void core1_loop()
{
    total_init::total_init_core1();
    /*Initialize LVGL*/
    lv_init();

    /*Set millisecond-based tick source for LVGL so that it can track time.*/
    lv_tick_set_cb(my_tick_cb);

    /*Create a display where screens and widgets can be added*/
    lv_display_t * display = lv_display_create(TFT_HOR_RES, TFT_VER_RES);

    /*Add rendering buffers to the screen.
     *Here adding a smaller partial buffer assuming 16-bit (RGB565 color format)*/
    static uint16_t buf1[TFT_HOR_RES * TFT_VER_RES / 10]; /* x2 because of 16-bit color depth */
    static uint16_t buf2[TFT_HOR_RES * TFT_VER_RES / 10];
    lv_display_set_buffers(display, buf1, buf2, sizeof(buf1), LV_DISPLAY_RENDER_MODE_PARTIAL);

    /*Add a callback that can flush the content from `buf` when it has been rendered*/
    lv_display_set_flush_cb(display, my_flush_cb);

    /*Create an input device for touch handling*/
    //lv_indev_t * indev = lv_indev_create();
    //lv_indev_set_type(indev, LV_INDEV_TYPE_POINTER);
    //lv_indev_set_read_cb(indev, my_touch_read_cb);

    lvgl_helper::init_all_ui_views();

    /*Execute the LVGL-related tasks in a loop*/
    
    while(1) {
    lv_timer_handler_run_in_period(5);
    lvgl_helper::check_layer_update();
}
}

int main(){
    // --- STEP 1: INITIALIZATION (Runs on Core 0) ---
    stdio_init_all();
    
    // Core 0 sets up the shared song queue, I2C, and UART
    total_init::total_init_core0();
    
    // Core 0 sets up the input encoders
    encoder_manager::init_encoders();

    // --- STEP 2: LAUNCH CORE 1 ---
    // Now that everything in memory is ready, wake up Core 1!
    multicore_launch_core1(core1_loop); 

    // --- STEP 3: CORE 0 MAIN LOOP ---
    // This main loop now belongs exclusively to Core 0
    while(1){
        encoder_manager::scan_encoders();
        song_info::check_buffer();
        total_init::check_failure();
        total_init::check_layer();
        uart_control::uart_read_inputs();
    }

    return 0; // The compiler is happy, but we never reach this
}

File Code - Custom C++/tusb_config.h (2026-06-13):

#ifndef _TUSB_CONFIG_H_
#define _TUSB_CONFIG_H_

#ifdef __cplusplus
 extern "C" {
#endif

//--------------------------------------------------------------------+
// Board Specific Configuration
//--------------------------------------------------------------------+

// RHPort number used for device can be defined by board.mk, default to port 0
#ifndef BOARD_TUD_RHPORT
#define BOARD_TUD_RHPORT      0
#endif

// RHPort max operational speed can defined by board.mk
#ifndef BOARD_TUD_MAX_SPEED
#define BOARD_TUD_MAX_SPEED   OPT_MODE_DEFAULT_SPEED
#endif

//--------------------------------------------------------------------
// COMMON CONFIGURATION
//--------------------------------------------------------------------

// defined by compiler flags for flexibility

#ifndef CFG_TUSB_OS
#define CFG_TUSB_OS           OPT_OS_NONE
#endif

#ifndef CFG_TUSB_DEBUG
#define CFG_TUSB_DEBUG        0
#endif

// Enable Device stack
#define CFG_TUD_ENABLED       1

// Default is max speed that hardware controller could support with on-chip PHY
#define CFG_TUD_MAX_SPEED     BOARD_TUD_MAX_SPEED

/* USB DMA on some MCUs can only access a specific SRAM region with restriction on alignment.
 * Tinyusb use follows macros to declare transferring memory so that they can be put
 * into those specific section.
 * e.g
 * - CFG_TUSB_MEM SECTION : __attribute__ (( section(".usb_ram") ))
 * - CFG_TUSB_MEM_ALIGN   : __attribute__ ((aligned(4)))
 */
#ifndef CFG_TUSB_MEM_SECTION
#define CFG_TUSB_MEM_SECTION
#endif

#ifndef CFG_TUSB_MEM_ALIGN
#define CFG_TUSB_MEM_ALIGN          __attribute__ ((aligned(4)))
#endif

//--------------------------------------------------------------------
// DEVICE CONFIGURATION
//--------------------------------------------------------------------

#ifndef CFG_TUD_ENDPOINT0_SIZE
#define CFG_TUD_ENDPOINT0_SIZE    64
#endif

//------------- CLASS -------------//
#define CFG_TUD_HID               1
#define CFG_TUD_CDC               1
#define CFG_TUD_MSC               0
#define CFG_TUD_MIDI              0
#define CFG_TUD_VENDOR            0

// HID buffer size Should be sufficient to hold ID (if any) + Data
#define CFG_TUD_HID_EP_BUFSIZE    16

// === ADD THESE LINES TO FIX THE COMPILER ERRORS ===
// CDC FIFO buffers (Used for USB Serial TX/RX)
#define CFG_TUD_CDC_RX_BUFSIZE    256
#define CFG_TUD_CDC_TX_BUFSIZE    256
#define CFG_TUD_CDC_EP_BUFSIZE    64

#ifdef __cplusplus
 }
#endif

#endif /* _TUSB_CONFIG_H_ */

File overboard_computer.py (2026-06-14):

import asyncio
import serial
import time
from winrt.windows.media.control import GlobalSystemMediaTransportControlsSessionManager as MediaManager

# --- Configuration ---
SERIAL_PORT = 'COM3'  # Update this to your device's actual COM port
BAUD_RATE = 115200
MAX_LENGTH = 127      # Matches (MAX_MESSAGE_LENGTH - 1) from your C++ code
POLL_INTERVAL = 1.0   # How often to check for song changes (in seconds)

async def get_current_media_info():
    """Fetches the currently playing song title and artist from Windows."""
    try:
        # Request access to the system media sessions
        sessions = await MediaManager.request_async()
        current_session = sessions.get_current_session()
        
        if current_session:
            # Try to grab the media properties asynchronously
            properties = await current_session.try_get_media_properties_async()
            if properties:
                title = properties.title
                artist = properties.artist
                
                # Format how you want it to appear on your display
                if title and artist:
                    return f"{title} - {artist}"
                elif title:
                    return title
        return None
    except Exception as e:
        # Occasional drops can happen if an app closes abruptly
        return None

def send_to_device(ser, track_name):
    """Truncates, packages, and sends the track info over serial."""
    if len(track_name) > MAX_LENGTH:
        track_name = track_name[:MAX_LENGTH]
        
    payload = f"{track_name}\n"
    try:
        ser.write(payload.encode('utf-8'))
        ser.flush()
        print(f"🎵 Now Displaying: {track_name}")
    except Exception as e:
        print(f"❌ Serial Error: {e}")

async def main():
    print(f"Connecting to device on {SERIAL_PORT}...")
    try:
        with serial.Serial(SERIAL_PORT, BAUD_RATE, timeout=1) as ser:
            print("✅ Connected! Monitoring Windows Media... (Press Ctrl+C to quit)")
            time.sleep(1) # Connection stability pause
            
            last_track = ""
            
            while True:
                # Fetch what Windows is currently playing
                current_track = await get_current_media_info()
                
                if current_track and current_track != last_track:
                    # Update the device only when a new song starts
                    send_to_device(ser, current_track)
                    last_track = current_track
                elif not current_track and last_track != "No Media Playing":
                    # Optional: Tell your device when nothing is playing anymore
                    send_to_device(ser, "No Media")
                    last_track = "No Media Playing"
                    
                # Wait before pulling media data again
                await asyncio.sleep(POLL_INTERVAL)
                
    except serial.SerialException:
        print(f"❌ Connection Failed. Is {SERIAL_PORT} plugged in or open elsewhere?")

if __name__ == "__main__":
    # Windows requires the asyncio loop to run to handle WinRT async calls
    asyncio.run(main())

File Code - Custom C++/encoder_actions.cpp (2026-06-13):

#include <cstdint>
#include "total_init.h"
#include "pico/stdlib.h"
#include "encoder_actions.h"
#include "tusb.h"

#define TOTAL_LAYERS 4
#define NUM_ENCODERS 3
#define TOTAL_ROTATIONS 2

bool encoder_actions::thud_que = 0;
uint32_t encoder_actions::ellapsed_thud = 0;
uint32_t encoder_actions::current_thud = 0;
uint16_t encoder_actions::empty_report = 0;
int16_t encoder_actions::enc3_physical_delta = 0;
bool encoder_actions::enc3_physical_button_pressed = false;

using encoder_array = void(*)(void);

constexpr encoder_array ENCODER_COMMAND_MATRIX[TOTAL_LAYERS][NUM_ENCODERS][TOTAL_ROTATIONS]{
    {
        {&encoder_actions::vol_up, &encoder_actions::vol_down}, //encoder 1 layer 1
        {&encoder_actions::next_track, &encoder_actions::prev_track},//encoder 2 layer 1
        {&encoder_actions::ui_up, &encoder_actions::ui_down}//encoder 3 layer 1
    },
    {
        //macro layer - no changes
        {&encoder_actions::vol_up, &encoder_actions::vol_down}, //encoder 1 layer 1
        {&encoder_actions::next_track, &encoder_actions::prev_track},//encoder 2 layer 1
        {&encoder_actions::ui_up, &encoder_actions::ui_down}//encoder 3 layer 1
    },
    {
        //led layer - brightness + lighting patterns
        {&total_init::increment_brightness, &total_init::decrement_brightness},
        {&total_init::increment_led_method, &total_init::decrement_led_method},
        {&encoder_actions::ui_up, &encoder_actions::ui_down}
    },
    {
        //sound board layer - dont know what to put here yet
        {&encoder_actions::vol_up, &encoder_actions::vol_down}, //encoder 1 layer 1
        {&encoder_actions::next_track, &encoder_actions::prev_track},//encoder 2 layer 1
        {&encoder_actions::ui_up, &encoder_actions::ui_down}//encoder 3 layer 1
    }
};

encoder_actions::encoder_actions()
{

}

encoder_actions::~encoder_actions()
{

}

void encoder_actions::handle_turn(uint8_t id, uint8_t rotation, uint8_t layer){
    ENCODER_COMMAND_MATRIX[layer][id][rotation]();
}

void encoder_actions::thud_start(uint16_t keycode){
    if(tud_hid_ready()){
        tud_hid_report(2, &keycode, sizeof(keycode));
        thud_que = true;
        ellapsed_thud = to_ms_since_boot(get_absolute_time());
    }
}

void encoder_actions::thud_scan(){
    if(thud_que != 0){
        current_thud = to_ms_since_boot(get_absolute_time());
        if(tud_hid_ready()){
            if(current_thud - ellapsed_thud >= 10){
                tud_hid_report(2, &empty_report, sizeof(empty_report));
                thud_que = false;
            }
        }
    }
}



void encoder_actions::vol_up(){
    thud_start(HID_USAGE_CONSUMER_VOLUME_INCREMENT);
}

void encoder_actions::vol_down(){
    thud_start(HID_USAGE_CONSUMER_VOLUME_DECREMENT);
}

void encoder_actions::next_track(){
    thud_start(HID_USAGE_CONSUMER_SCAN_NEXT);
}

void encoder_actions::prev_track(){
    thud_start(HID_USAGE_CONSUMER_SCAN_PREVIOUS);
}

void encoder_actions::ui_up(){
    enc3_physical_delta++;
}

void encoder_actions::ui_down(){
    enc3_physical_delta--;
}

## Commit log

2026-06-01 Finalized PCB files
    [keyboard.kicad_sch]
2026-06-13 Revise README with project details and specifications
    Updated project description and added key features, images, and BOM details.
2026-06-13 Refactor BOM formatting in README.md
    Updated the Bill of Materials (BOM) section to remove extra spaces.
2026-06-23 added stl files
    [Keyboard_bottom.stl, Keyboard_top.stl]
2026-07-05 updated readibility
    [Bottom_Case.step, Keyboard_bottom.stl, Keyboard_top.stl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]
2026-08-07 Revise BOM with updated component links and counts
    Updated BOM with new links and quantities for components.
2026-08-07 Add hyperlinks to components in README
    Updated component list with hyperlinks for Raspberry Pi Pico, Mini 560 5A 5V, and Adafruit 5807 Power Evaluation Board.
2026-08-07 Update BOM with new product links
2026-08-07 Update BOM with new components and pricing
    Updated BOM.csv to include additional components and their details.
    [BOM.csv]
2026-08-08 Enhance README formatting and add BOM as CSV
    Updated README to improve formatting and add links.
2026-08-08 Update BOM.csv with custom PCB and new total
    [BOM.csv]
2026-08-08 upload new hand placed keys
    [keyboard-B_Cu.gbr, keyboard-B_Mask.gbr, keyboard-B_Paste.gbr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]
2026-08-08 Add flashing instructions for pi pico and pi pico 2
    Added instructions for flashing the pi pico and pi pico 2, including compiling steps and file uploads. Along with BOM and image revisions.
2026-08-08 Revise flashing instructions in README
    Updated flashing instructions for pi pico and pi pico 2.
2026-08-08 Fix header formatting and clarify flashing instructions
    Corrected formatting for the 'Flashing' section header and improved clarity in instructions for flashing the Pi Pico.
